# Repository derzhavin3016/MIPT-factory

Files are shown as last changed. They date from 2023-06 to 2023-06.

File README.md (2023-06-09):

# Колёсно-гусеничный модульный бот

## Состав команды
- Оклей Антон Павлович **разработка 3D моделей деталей шасси**
- Сидельников Станислав Игоревич **сборка, подгонка деталей, 
тестирование и разработка деталей гусеницы** 
- Державин Андрей Андреевич **разработка ПО для управления**

## Описание продукта
Радиоуправляемый бот, состоящий из нескольких модулей, с возможностью 
передвигаться как на колесном, так и на гусеничном ходу. Кроме этого, при 
движении на колесах, бот может передвигаться под углом, так как все три 
пары колес соединены и поворачивают одновременно.

## Существующие аналоги

### Пример колесного автомобиля с возможностью передвижения под углом

#### Arquus Scarabee



Организованное таким образом движение упрощает проезд в узких пространствах.

### Примеры колесно-гусеничных машин

#### Танк БТ-2 с надетыми гусеницами

изображение

#### Танк БТ-2 со снятыми гусеницами

изображение

## Цель проекта

Создать базовые модули, на основе которых можно собрать бота в 
зависимости от поставленной задачи.

### Процесс создания

Сначала были разработаны модели всех необходимых деталей в SolidWorks
для дальнейшей печати на 3D-принтере

изображение

После подгонки всех деталей друг к другу, был спроектирован трак для 
дальнейшей печати гусеницы

изображение

> Печать траков занимает достаточно продолжительное время, на данный 
> момент готов только небольшой сегмент гусеницы.

Затем было произведено подключение всех компонентов друг к другу и 
проведение ходовых испытаний.

## Результаты

Собранный прототип успешно прошел ходовые испытания. Все функции 
работают должным образом. Проверка движения на гусеничном ходу не 
была проведена, так как на данный момент напечатано недостаточно много 
траков для сборки двух полноценных гусениц

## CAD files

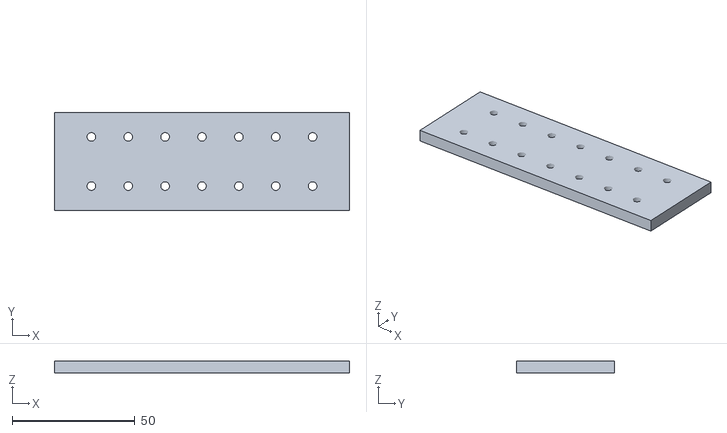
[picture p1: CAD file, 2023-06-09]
STL/Соединение.STL
120.0 x 40.0 x 5.00

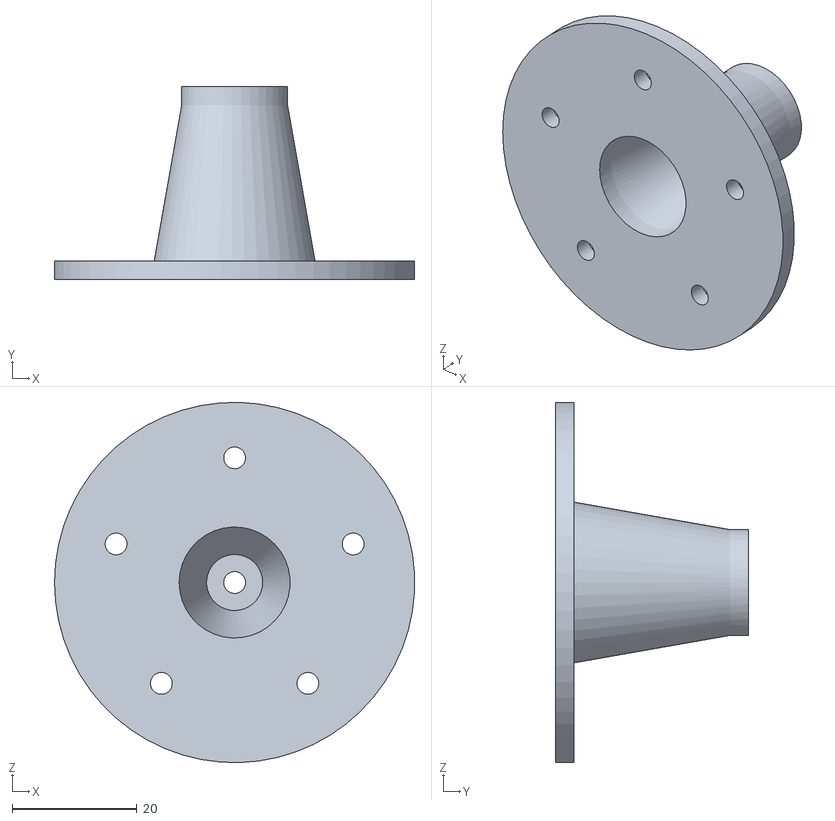
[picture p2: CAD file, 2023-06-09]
STL/Крепление_диска.STL
57.8 x 31.0 x 57.8

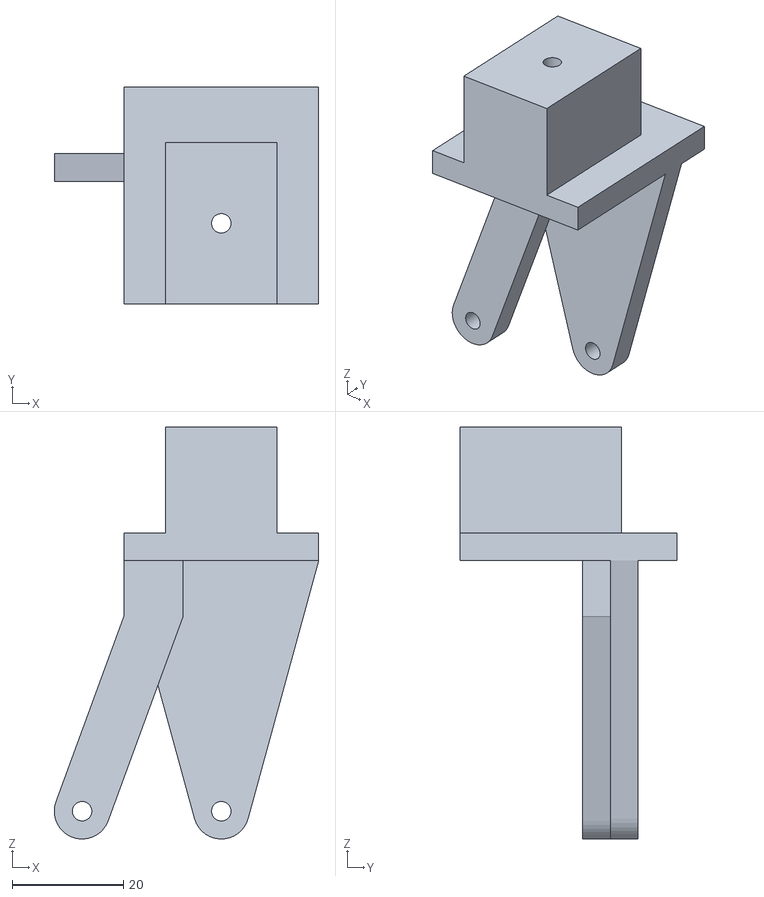
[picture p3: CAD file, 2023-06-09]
STL/колесо_крепление.STL
47.5 x 39.0 x 74.0

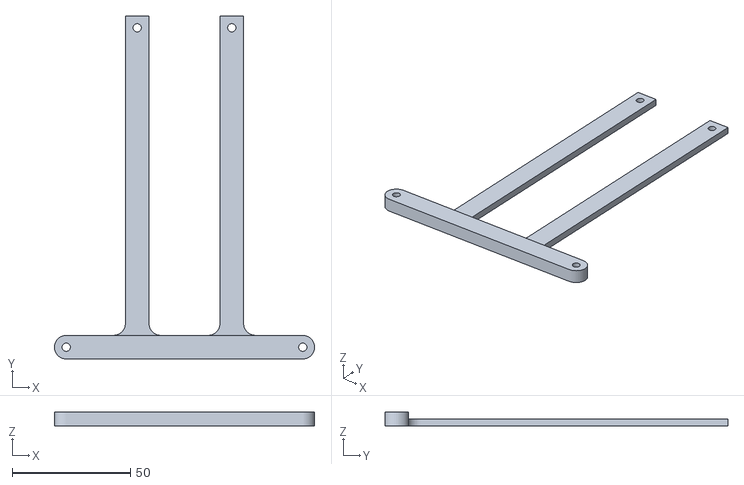
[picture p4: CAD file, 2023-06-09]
STL/turn_connector_edge.STL
110.0 x 145.0 x 6.00

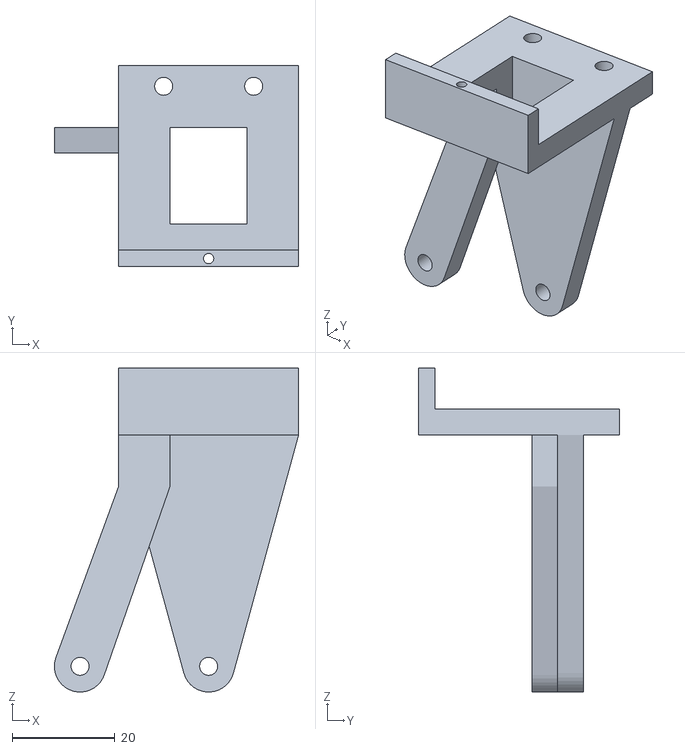
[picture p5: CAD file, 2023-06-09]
STL/мотор_крепление.STL
47.5 x 39.0 x 63.0

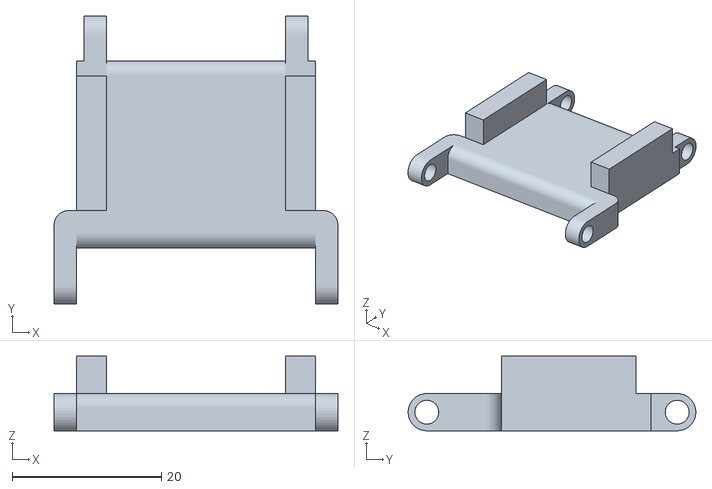
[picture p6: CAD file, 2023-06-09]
STL/Трак.STL
38.0 x 38.5 x 10.0

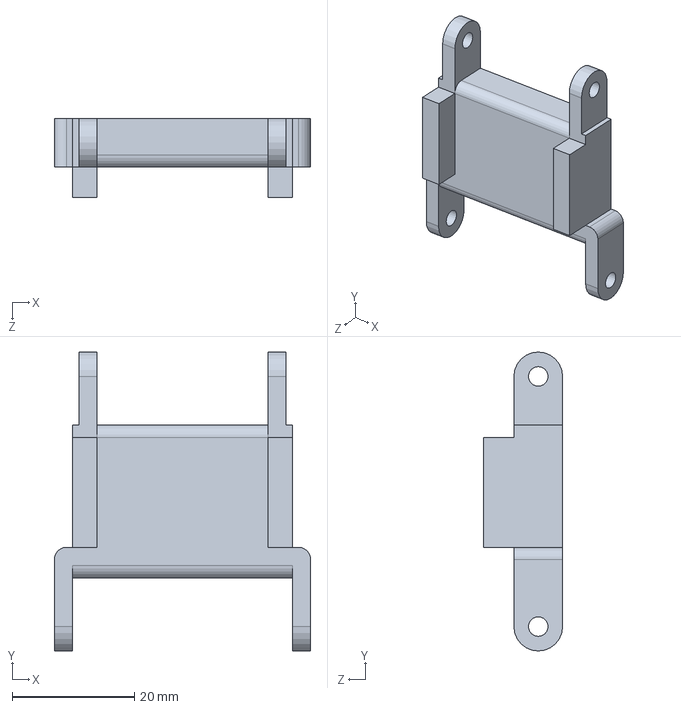
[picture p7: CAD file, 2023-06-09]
STL/Track.SLDPRT
42.0 x 49.0 x 13.0 mm

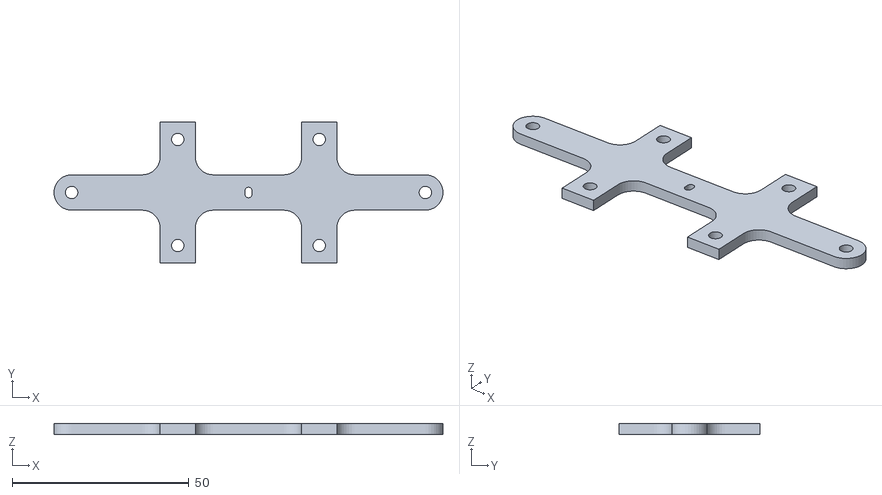
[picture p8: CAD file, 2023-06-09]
STL/turn_connector.STL
110.0 x 40.0 x 3.00

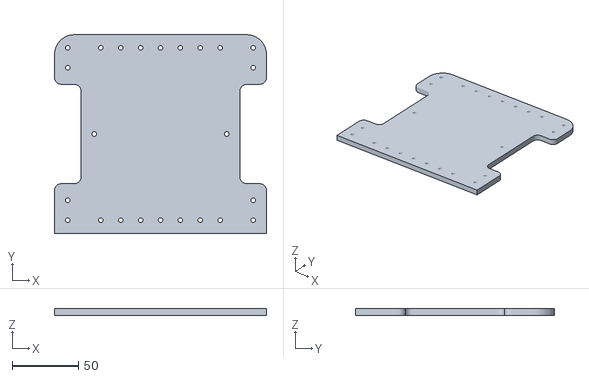
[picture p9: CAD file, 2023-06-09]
STL/Днище_крайний_модуль.STL
160.0 x 150.0 x 5.00

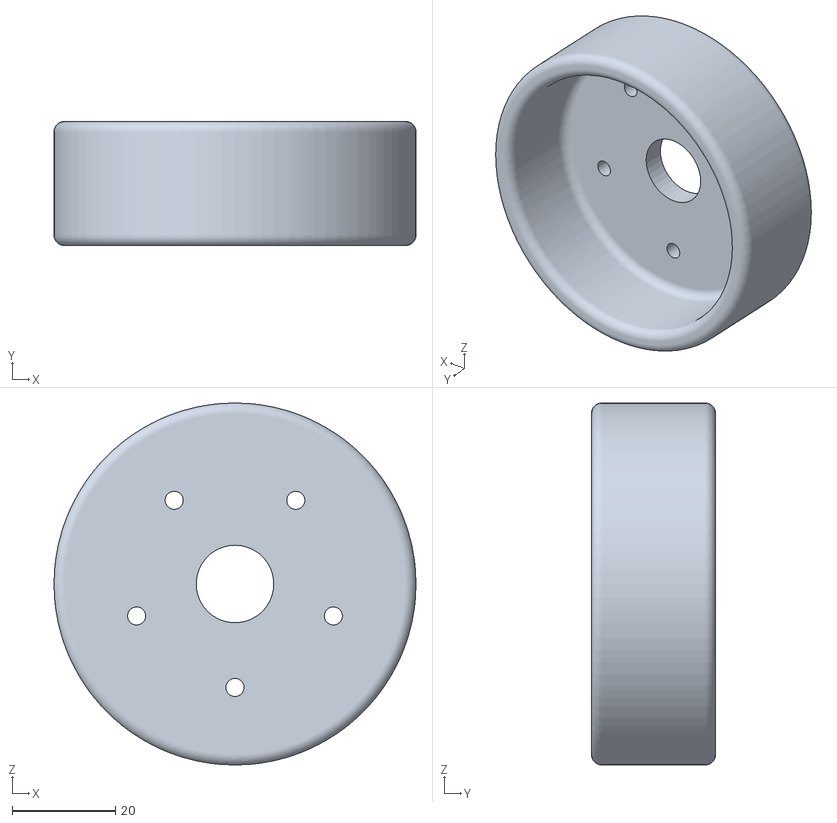
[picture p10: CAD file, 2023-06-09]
STL/Ведущее_колесо.STL
70.0 x 24.0 x 70.0

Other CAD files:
STL/Крепление_диска_мотор.STL
STL/Track.STL

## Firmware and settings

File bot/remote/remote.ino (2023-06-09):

#include "remote.h"

RF24 radio_gaga(9, 10);
int data[5];

constexpr int xPin = A0;
constexpr int yPin = A1;
constexpr int buttonPin = 4;
constexpr int ptmrPin = A4;
constexpr int tumblrPin = 0;

int xPosition = 0;
int yPosition = 0;
int buttonState = 0;
int tumblrState = 0;
int ptmrState = 0;

int speed = 0;
int direction = 0;

void setup()
{
  Serial.begin(9600);
  setup_radio(radio_gaga);
  radio_gaga.openWritingPipe(pipeAddr);

  pinMode(xPin, INPUT);
  pinMode(yPin, INPUT);
  pinMode(buttonPin, INPUT_PULLUP);
  pinMode(tumblrPin, INPUT);
  pinMode(ptmrPin, INPUT);
}
constexpr int DEAD_HIGH = 562;
constexpr int DEAD_LOW = 462;

void loop()
{
  xPosition = analogRead(xPin);
  yPosition = analogRead(yPin);
  buttonState = digitalRead(buttonPin);
  tumblrState = digitalRead(tumblrPin);
  ptmrState = analogRead(ptmrPin);

  if (xPosition > DEAD_HIGH)
  {
    // go forward
    Serial.println("FORWARD");
    direction = Dir::FORWARD;
    speed = map(xPosition, DEAD_HIGH, 1023, 5, 255);
  }
  else if (xPosition < DEAD_LOW)
  {
    // go backward
    Serial.println("BACKWARD");
    direction = Dir::BACKWARD;
    speed = map(xPosition, DEAD_LOW, 0, 5, 255);
  }
  else
  {
    Serial.println("NO");
    direction = Dir::NO;
    speed = 0;
  }

  auto rot_angle = map(yPosition, 0, 1023, LEFT_ROT, RIGHT_ROT);

  data[0] = direction;
  data[1] = speed;
  data[2] = rot_angle;
  data[3] = tumblrState;
  data[4] = ptmrState;
  if (radio_gaga.write(&data, sizeof(data)))
    Serial.println(
      "SEND"); // check delivery: if(radio.write(&data, sizeof(data)))

  // Serial.println(ptmrState);

  // Serial.println(speed);
  // delay(100);
}

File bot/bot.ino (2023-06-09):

#include "remote/remote.h"
#include <Servo.h>

RF24 radio_gugu(9, 10);

constexpr unsigned DATA_SIZE = 5;
int data[DATA_SIZE];// = {-1, -1};

struct ServAngle
{
private:
  Servo servo_{};

public:
  void attach(int pin)
  {
    servo_.attach(pin);
  }

  void noRotate()
  {
    servo_.write(DEFAULT_ANGLE);
  }

  void rotateRight()
  {
    servo_.write(RIGHT_ROT);
  }

  void rotateLeft()
  {
    servo_.write(LEFT_ROT);
  }

  void rotate(int angle)
  {
    if (angle <= RIGHT_ROT && angle >= LEFT_ROT)
      servo_.write(angle);
  }
} serv;

constexpr int SERVO_PIN = 8;

void setup()
{
  Serial.begin(9600);

  setup_radio(radio_gugu);
  radio_gugu.openReadingPipe(1, pipeAddr);
  radio_gugu.startListening();

  // motor pins
  for (int i = 4; i < 8; ++i)
    pinMode(i, OUTPUT);

  Serial.println("RADIO GUGU START");

  serv.attach(SERVO_PIN);
}

constexpr int SPEED_1 = 5;
constexpr int DIR_1 = 4;
constexpr int SPEED_2 = 6;
constexpr int DIR_2 = 7;

void loop()
{
  static int def = 0;
  if (!def)
    serv.noRotate(), def = 1;

  if (!radio_gugu.available())
    return;

  radio_gugu.read(&data, sizeof(data));
  Serial.println("RADIO GUGU");
  Serial.println(data[0]);
  Serial.println(data[1]);

  auto rot_angle = data[2];
  auto tmblrState = data[3];
  auto ptmrVal = data[4];

  processDir(data[0], data[1]);
  serv.rotate(rot_angle);
}

void setEngine(int dir1, int dir2, int spd)
{
  digitalWrite(DIR_1, dir1);
  analogWrite(SPEED_1, spd);

  digitalWrite(DIR_2, dir2);
  analogWrite(SPEED_2, spd);
}

void processDir(int dir, int spd)
{
  switch (dir)
  {
  case Dir::FORWARD:
    setEngine(LOW, LOW, spd);
    break;
  case Dir::BACKWARD:
    setEngine(HIGH, HIGH, spd);
    break;
  case Dir::RIGHT:
    setEngine(HIGH, LOW, spd);
    break;
  case Dir::LEFT:
    setEngine(LOW, HIGH, spd);
    break;
  default:
    setEngine(HIGH, HIGH, 0);
    Serial.println("No direction");
  }
}

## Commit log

2023-05-19 Servo test
2023-06-08 Add servo angles constants
2023-06-09 Add STL files
    [Track.SLDPRT, Track.STL, turn_connector.STL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]
